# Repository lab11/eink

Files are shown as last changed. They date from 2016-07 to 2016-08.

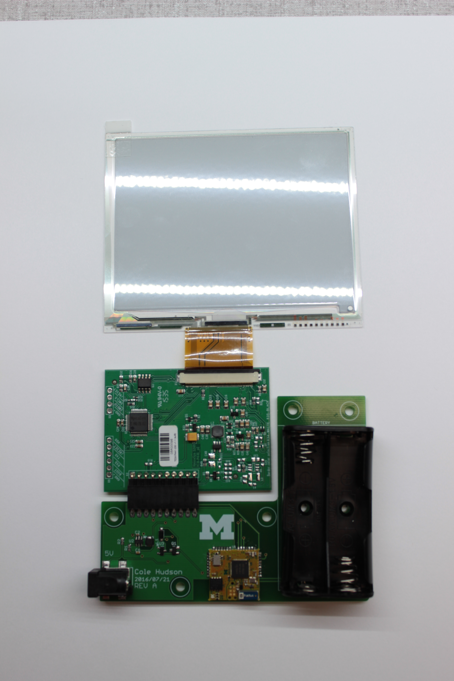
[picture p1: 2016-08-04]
media/IMG_8517.JPG

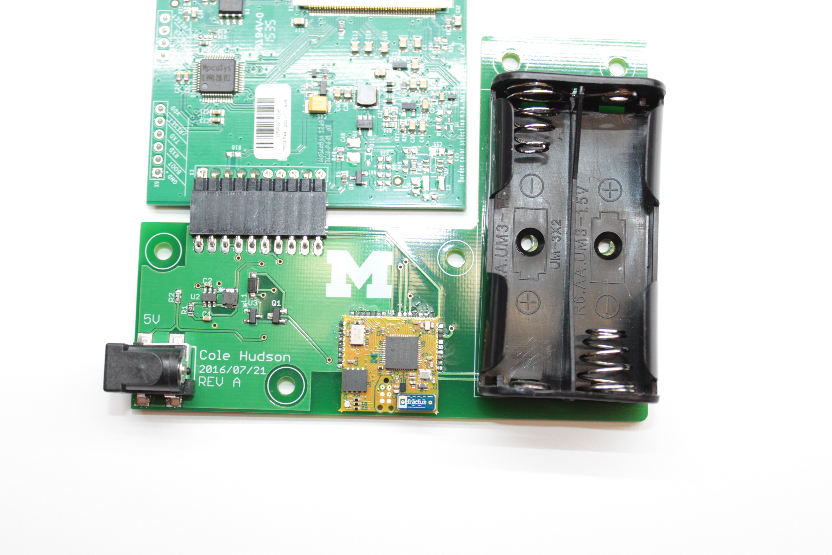
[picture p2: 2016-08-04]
media/IMG_8522.JPG

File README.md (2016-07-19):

# E-Ink
This is a BLE-controlled e-ink display built off of the nrf51822.

## Software
The nrf software can be found in ``` /software/nrf5x-base/apps/eink-advanced/ ```

## Summon App
[Summon](https://github.com/lab11/summon) is a UI application for BLE devices. Rather than requiring every user to install a new app for every BLE device, Summon allows BLE devices to point to their own HTML/JS based interface and loads it in a single application. Eink supports the summon architecture and provides a Summon application.

## Hardware
The hardware is built on top of the nrf51822. A full parts list can be found in the ``` /hardware ``` directory, along with pcb and case designs.

## API

| Characteristic name | uuid | Data Type | Range |
| --- | --- | --- | ---
| service | e528a44a-ff4f-3089-d44f-7cb505aba641 | None | |
| text | e528a410-ff4f-3089-d44f-7cb505aba641 | 20 byte packets up to 60 bytes | |
| x coordinate | e528a411-ff4f-3089-d44f-7cb505aba641 | uint16_t | 0 - 400 |
| y coordinate | e528a412-ff4f-3089-d44f-7cb505aba641 | uint16_t | 0 - 300 |
| scale | e528a413-ff4f-3089-d44f-7cb505aba641 | uint8_t | 0 - 10  |
| qrcode | e528a414-ff4f-3089-d44f-7cb505aba641 | 20 bytes | |
| control | e528a415-ff4f-3089-d44f-7cb505aba641 | uint8_t | |

#### Text
~~1. Break your text up into 19-byte packets.
2. Create an array of these packets.
3. For each packet, make the first byte equal to its distance from the last packet (the first byte of the first packet would be chunks.length - 1, the first byte of the last packet will be 0).
4. The remaining bytes will be the text packet.~~

**You can only write 18 characters at a time.**

#### Control
Writing 1 to control will refresh the display to show changes that have been made.
Writing 2 to control will clear the screen.

### Example

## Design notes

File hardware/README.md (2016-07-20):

#Parts

| Name | Price  | Link |
| --- | --- | --- |
| Eink Display | $66.00 | http://www.digikey.com/product-detail/en/ST044AS182/ST044AS182-ND/4898786 |
| Female headers  | $00.94 | http://www.digikey.com/product-detail/en/sullins-connector-solutions/PPTC101LGBN-RC/S5446-ND/775904 |
| Inductor | $00.48 | http://www.digikey.com/product-detail/en/murata-electronics-north-america/LQH43CN100K03L/490-2519-1-ND/599992 |
| 10uF capacitor  | $00.12 | http://www.digikey.com/product-detail/en/murata-electronics-north-america/GRM155R60G106ME44D/490-10693-1-ND/5251412 |
| 2.2uf capacitor | $00.12 | http://www.digikey.com/product-detail/en/murata-electronics-north-america/GRM188R61C225KE15D/490-3296-1-ND/702837 |
| Max6326 | $03.11 | http://www.digikey.com/product-detail/en/maxim-integrated/MAX6326UR29-T/MAX6326UR29-TCT-ND/2234432 |
| Mosfet | $00.39 | http://www.digikey.com/product-detail/en/fairchild-semiconductor/FDN340P/FDN340PCT-ND/965604 |
| Diode | $00.38 | http://www.digikey.com/product-detail/en/fairchild-semiconductor/SS15FA/SS15FACT-ND/5892131 |
| Barrel Jack | $01.89 | http://www.digikey.com/product-detail/en/cui-inc/PJ-002AH-SMT-TR/CP-002AHPJCT-ND/669692 |

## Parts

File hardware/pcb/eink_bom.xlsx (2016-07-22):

Qty | Value | Device | Package | Parts | Description | DIGIKEY | MPN | OC_FARNELL | OC_NEWARK | PACKAGE | PROD_ID | SF_ID | SUPPLIER | TOLERANCE | VALUE | WATTAGE
1 |  | DIODE[SCHOTKY]-SOD123W | SOD123W | D1 |  | SS15FACT-ND
1 |  | PINHD-1X10/90 | 1X10/90 | JP1 | PIN HEADER | S5446-ND
1 | 100K Ohms | RC0603JR-07100KL | RESC1608X60N | R1 | RESISTOR, 0603 | 311-100KGRCT-ND | RC0603JR-07100KL | 9233628 | 98K7287 |  |  |  | Yageo | ±5% | 100K Ohms | 1/10 W
1 | 100K Ohms | RC0603JR-07100KL | RESC1608X60N | R2 | RESISTOR, 0603 |  | RC0603JR-07100KL | 9233628 | 98K7287 |  |  |  | Yageo | ±5% | 100K Ohms | 1/10 W
1 | 10uF | CAPACITOR | 0402_CAP | C2 | 0402 Capacitor | 490-10693-1-ND
1 | 2.2uF | CAPACITOR | 0402_CAP | C1 | 0402 Capacitor | 490-3296-1-ND
1 | 5.5x2.1mm Barrel | POWER_JACKSMD | POWER_JACK_SMD | J2 | Power Jack | CP-002AHPJCT-ND |  |  |  |  | CONN-08106 | PRT-12748 |  |  | 5.5x2.1mm Barrel
1 | FDN340P | FDN340P | SSOT-3 | Q1 | P-Channel MOSFET | FDN340PCT-ND
1 | KEYSTONEELECTRONICS2462 | KEYSTONEELECTRONICS2462 | KEYSTONEELECTRONICS2462 | BATTERY |  | 36-2462-ND
1 | LTC3531ES6-3PBF | LTC3531ES6-3PBF | SOT95P280X100-6N | U2 | DC/DC Converters | LTC3531ES6-3.3#TRMPBFCT-ND | LTC3531ES6-3#PBF | - | 46P4583 | TSOT-23-6 |  |  | Linear Technology
1 | MAX6326UR29+ | MAX6326UR29+ | SOT95P228X119-3N | U3 | 3-Pin, Ultra-Low-Power SC70/SOT ìP Reset Circuits | MAX6326UR29+TCT-ND | MAX6326UR29+ | 9723951 | - | SOT-23-3 |  |  | Maxim
1 | NUCLEUM | NUCLEUM | NUCLEUM | U1 | Nucleum sensorboard prototyping module.
1 | UMICH_SOLID_LARGE | UMICH_SOLID_LARGE | UMICH_SOLID_350MIL | LOGO1
1 | VLF302510MT | VLF302510MT | VLF302510MT | L1 | POWER INDUCTOR | 445-6775-1-ND

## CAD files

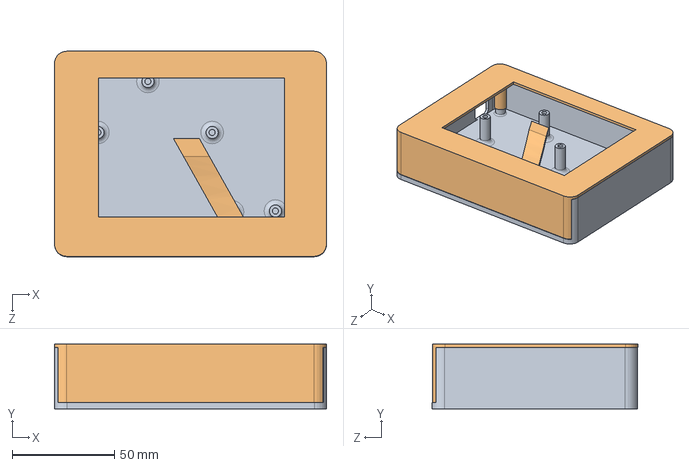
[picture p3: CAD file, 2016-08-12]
hardware/case/eink_assembly.SLDASM
133.3 x 31.8 x 100.8 mm
eink_controller_case_back_test
eink_controller_case_front_test2

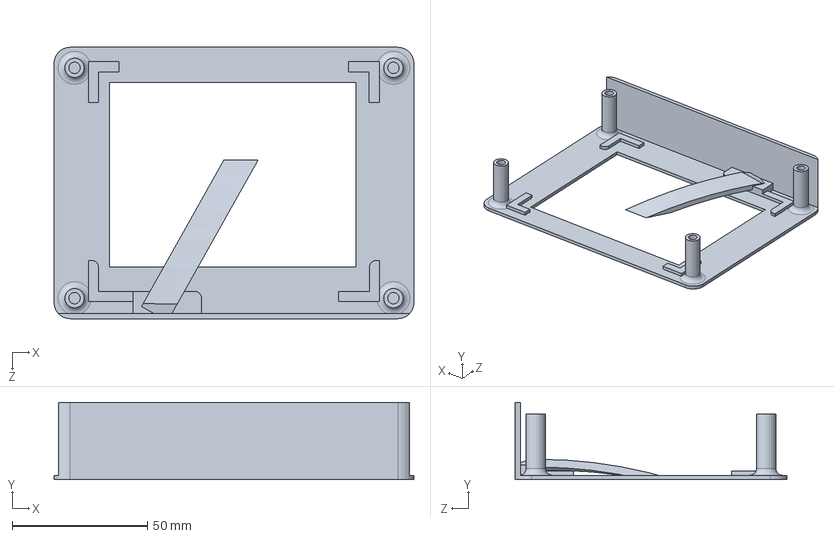
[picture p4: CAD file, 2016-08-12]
hardware/case/eink_controller_case_front_test2.SLDPRT
133.3 x 28.6 x 100.5 mm

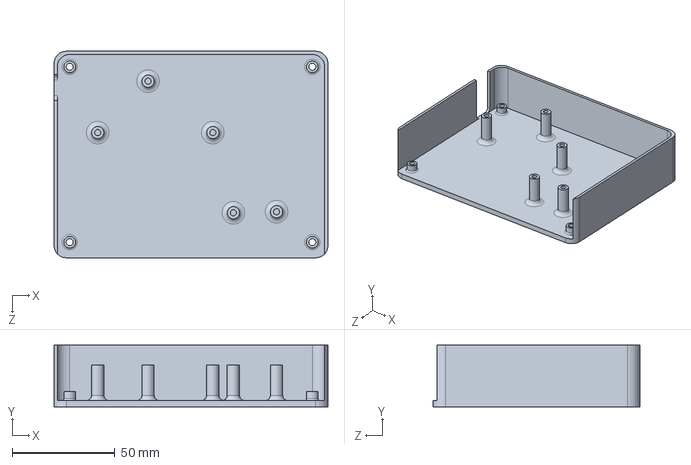
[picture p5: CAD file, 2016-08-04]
hardware/case/eink_controller_case_back_test.SLDPRT
133.3 x 30.2 x 100.5 mm

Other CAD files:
hardware/case/eink_controller_case_front.STL

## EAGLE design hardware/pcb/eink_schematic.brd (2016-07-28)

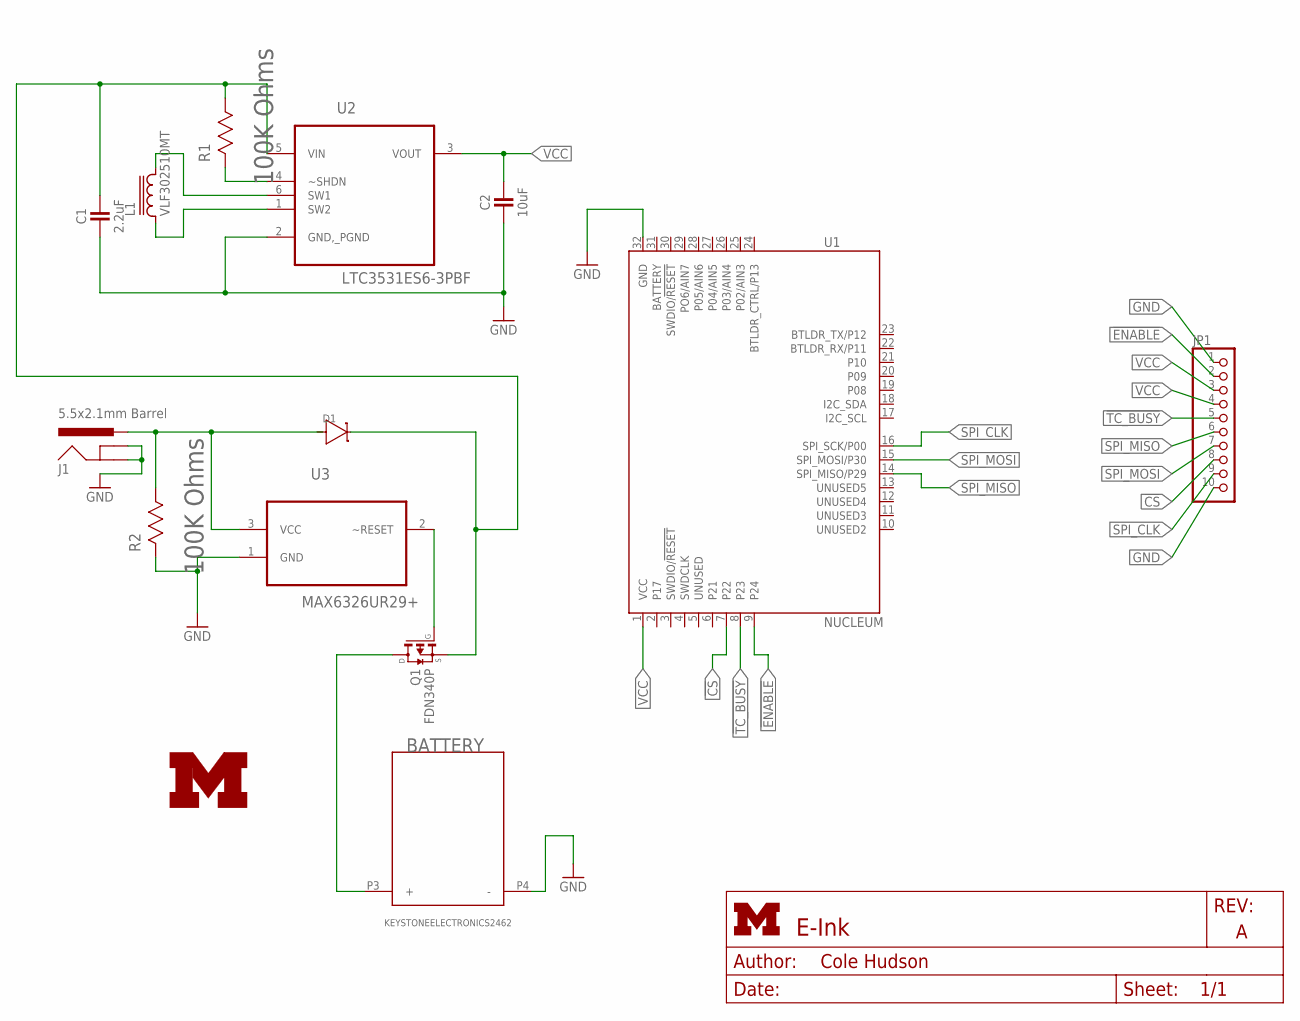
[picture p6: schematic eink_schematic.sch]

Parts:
BATTERY: KEYSTONEELECTRONICS2462; DIGIKEY 36-2462-ND
C1: 2.2uF; 0402_CAP; DIGIKEY 490-3296-1-ND
C2: 10uF; 0402_CAP; DIGIKEY 490-10693-1-ND
D1: DIODE[SCHOTKY]-SOD123W; SOD123W; DIGIKEY SS15FACT-ND
J1: 5.5x2.1mm Barrel; POWER_JACK_SMD; DIGIKEY CP-002AHPJCT-ND
JP1: PINHD-1X10/90; 1X10/90; DIGIKEY S5446-ND
L1: VLF302510MT; DIGIKEY 445-6775-1-ND
LOGO1: UMICH_SOLID_LARGE; UMICH_SOLID_350MIL
Q1: FDN340P; SSOT-3; DIGIKEY FDN340PCT-ND
R1: 100K Ohms; RESC1608X60N; DIGIKEY 311-100KGRCT-ND
R2: 100K Ohms; RESC1608X60N
U1: NUCLEUM
U2: LTC3531ES6-3PBF; SOT95P280X100-6N; DIGIKEY LTC3531ES6-3.3#TRMPBFCT-ND
U3: MAX6326UR29+; SOT95P228X119-3N; DIGIKEY MAX6326UR29+TCT-ND

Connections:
!CS: JP1.8, U1.7 (P22)
!ENABLE: JP1.2, U1.9 (P24)
!SHDN: R1.2 (R2), U2.4 (~SHDN)
!TC_BUSY: JP1.5, U1.8 (P23)
GND: BATTERY.P4 (-), C1.2, C2.2, J1.GND (GNDBREAK), J1.P$4 (GND), JP1.1, JP1.10, R2.2 (R2), U1.32 (GND), U2.2 (GND,_PGND), U3.1 (GND)
unnamed: Q1.1 (G), U3.2 (~RESET)
unnamed: D1.P$1 (1), J1.VIN0 (PWR), R2.1 (R1), U3.3 (VCC)
unnamed: C1.1, D1.P$2 (2), Q1.2 (S), R1.1 (R1), U2.5 (VIN)
unnamed: BATTERY.P3 (+), Q1.3 (D)
SPI_CLK: JP1.9, U1.16 (SPI_SCK/P00)
SPI_MISO: JP1.6, U1.14 (SPI_MISO/P29)
SPI_MOSI: JP1.7, U1.15 (SPI_MOSI/P30)
SW1: L1.2, U2.6 (SW1)
SW2: L1.1, U2.1 (SW2)
VCC: C2.1, JP1.3, JP1.4, U1.1 (VCC), U2.3 (VOUT)

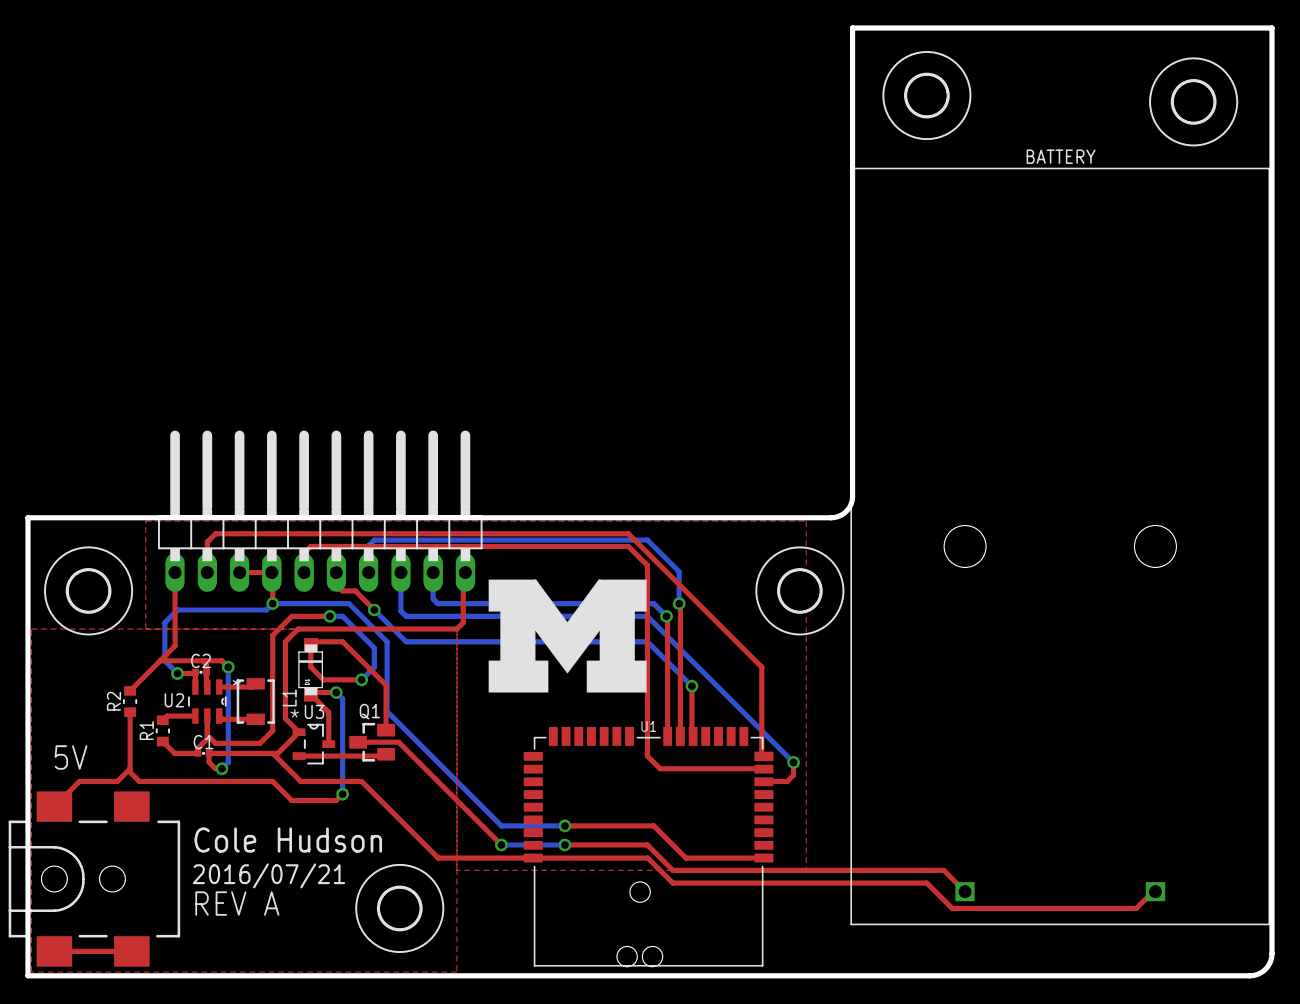
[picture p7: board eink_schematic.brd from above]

Board: 2 copper layers, 97.9 x 74.6 mm, 19 parts (0 on the bottom side), 15 nets.

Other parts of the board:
U$1, U$2, U$3, U$4, U$5: 3,2

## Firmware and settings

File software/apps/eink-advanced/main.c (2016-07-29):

#include <stdbool.h>
#include <stdint.h>

// Nordic libraries
#include "ble_advdata.h"
#include "nordic_common.h"
#include "softdevice_handler.h"

// nrf5x-base libraries
#include "simple_ble.h"
#include "simple_adv.h"
#include "led.h"
#include "device_info_service.h"

#include "eddystone.h"

#include "tcmp441.h"

// Define constants about this beacon.
#define DEVICE_NAME "E-Ink disp"
#define PHYSWEB_URL "goo.gl/pKiLW5"

#define LED0 18
#define LED1 19
#define LED2 20

// Intervals for advertising and connections
static simple_ble_config_t ble_config = {
    .platform_id       = 0x00,              // used as 4th octect in device BLE address
    .device_id         = DEVICE_ID_DEFAULT,
    .adv_name          = DEVICE_NAME,       // used in advertisements if there is room
    .adv_interval      = MSEC_TO_UNITS(500, UNIT_0_625_MS),
    .min_conn_interval = MSEC_TO_UNITS(500, UNIT_1_25_MS),
    .max_conn_interval = MSEC_TO_UNITS(1000, UNIT_1_25_MS)
};

// service and characteristic handles
//  UUID created by `uuidgen -r`
//  16-bit short uuid is 0x890f (bytes 12 and 13 of 128-bit UUID)
static simple_ble_service_t eink_service = {
    .uuid128 = {{0x41, 0xa6, 0xab, 0x05, 0xb5, 0x7c, 0x4f, 0xd4,
                 0x89, 0x30, 0x4f, 0xff, 0xa4, 0x4a, 0x28, 0xe5}}
};

//text x coordinate
static simple_ble_char_t text_x_coordinate_char = {.uuid16 = 0xa411};
static uint16_t text_x_coordinate_value = 0;

//text y coordinate
static simple_ble_char_t text_y_coordinate_char = {.uuid16 = 0xa412};
static uint16_t text_y_coordinate_value = 0;

//text scale
static simple_ble_char_t text_scale_char = {.uuid16 = 0xa413};
static uint8_t text_scale_value = 1;//default to 1

//text
static simple_ble_char_t text_char = {.uuid16 = 0xa410};
static char text_value[30] = {0};

//qr code
static simple_ble_char_t qrcode_char = {.uuid16 = 0xa414};
static char qrcode_value[52] = {0};

//control characteristic 
static simple_ble_char_t control_char = {.uuid16 = 0xa415};
static uint8_t control_value = 0;//0 = nothing, 1 = refresh, 2 = clear

static volatile uint8_t second=0;

// called automatically by simple_ble_init
void services_init (void) {
    // add led service
    simple_ble_add_service(&eink_service);

    //add text x coordinate
    simple_ble_add_characteristic(0, 1, 0, 0,
            2, (uint16_t*)&text_x_coordinate_value,
            &eink_service, &text_x_coordinate_char);

    //add text y coordinate
    simple_ble_add_characteristic(0, 1, 0, 0,
            2, (uint16_t*)&text_y_coordinate_value,
            &eink_service, &text_y_coordinate_char);

    //add text scale
    simple_ble_add_characteristic(0, 1, 0, 0,
            1, (uint8_t*)&text_scale_value,
            &eink_service, &text_scale_char);

    //add string
    simple_ble_add_characteristic(0, 1, 0, 0,
            30, (char*)&text_value,
            &eink_service, &text_char);

    //add qr code
    simple_ble_add_characteristic(0, 1, 0, 0,
            52, (char*)&qrcode_value,
            &eink_service, &qrcode_char);

    //add control char
    simple_ble_add_characteristic(0, 1, 0, 0,
            1, (uint8_t*)&control_value,
            &eink_service, &control_char);
}

void ble_evt_write(ble_evt_t* p_ble_evt) 
{
    if (simple_ble_is_char_event(p_ble_evt, &text_char)) 
    {
        tcmp441_writeStringAtLocation(text_value, text_x_coordinate_value, text_y_coordinate_value, text_scale_value);
    }
    else if(simple_ble_is_char_event(p_ble_evt, &control_char))
    {
        if(control_value == 1)
        {
            //refresh
            tcmp441_updateDisplay();
        }
        else if(control_value == 2)
        {
            //clear
            tcmp441_clearScreen();
            tcmp441_updateDisplay();
        }
    }
    else if(simple_ble_is_char_event(p_ble_evt, &qrcode_char))
    {
        tcmp441_writeQRcode(qrcode_value);
    }
}

void ble_evt_connected(ble_evt_t* p_ble_evt)
{
    led_on(LED0);
}

void ble_evt_disconnected(ble_evt_t* p_ble_evt)
{
    led_off(LED0);
}

int main(void) 
{
    //set up the led, spi, and bluetooth
    tcmp441_init(18, 19, 20, 24, 23, 22);

    //write to the screen array and then update the display
    //writeQRcode("http://eecs.umich.edu");
    //updateDisplay();

    simple_ble_init(&ble_config);
    simple_adv_only_name();

    //advertise url
    eddystone_adv(PHYSWEB_URL, NULL);

    //writeStringAtLocation("Booted up", 0, 0, 2);
    //updateDisplay();

    //led_on(LED0);

    tcmp441_clearScreen();
    tcmp441_updateDisplay();

    // Enter main loop.
    while (1) {
        sd_app_evt_wait();
        //power_manage();
    }
}

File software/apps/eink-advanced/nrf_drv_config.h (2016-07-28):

/* Copyright (c) 2015 Nordic Semiconductor. All Rights Reserved.
 *
 * The information contained herein is property of Nordic Semiconductor ASA.
 * Terms and conditions of usage are described in detail in NORDIC
 * SEMICONDUCTOR STANDARD SOFTWARE LICENSE AGREEMENT.
 *
 * Licensees are granted free, non-transferable use of the information. NO
 * WARRANTY of ANY KIND is provided. This heading must NOT be removed from
 * the file.
 *
 */

#ifndef NRF_DRV_CONFIG_H
#define NRF_DRV_CONFIG_H

/**
 * Provide a non-zero value here in applications that need to use several
 * peripherals with the same ID that are sharing certain resources
 * (for example, SPI0 and TWI0). Obviously, such peripherals cannot be used
 * simultaneously. Therefore, this definition allows to initialize the driver
 * for another peripheral from a given group only after the previously used one
 * is uninitialized. Normally, this is not possible, because interrupt handlers
 * are implemented in individual drivers.
 * This functionality requires a more complicated interrupt handling and driver
 * initialization, hence it is not always desirable to use it.
 */
#define PERIPHERAL_RESOURCE_SHARING_ENABLED  0

/* CLOCK */
#define CLOCK_ENABLED 0

#if (CLOCK_ENABLED == 1)
#define CLOCK_CONFIG_XTAL_FREQ          NRF_CLOCK_XTALFREQ_Default
#define CLOCK_CONFIG_LF_SRC             NRF_CLOCK_LF_SRC_Xtal
#define CLOCK_CONFIG_IRQ_PRIORITY       APP_IRQ_PRIORITY_LOW
#endif

/* GPIOTE */
#define GPIOTE_ENABLED 1

#if (GPIOTE_ENABLED == 1)
#define GPIOTE_CONFIG_USE_SWI_EGU false
#define GPIOTE_CONFIG_IRQ_PRIORITY APP_IRQ_PRIORITY_LOW
#define GPIOTE_CONFIG_NUM_OF_LOW_POWER_EVENTS 1
#endif

/* TIMER */
#define TIMER0_ENABLED 0

#if (TIMER0_ENABLED == 1)
#define TIMER0_CONFIG_FREQUENCY    NRF_TIMER_FREQ_16MHz
#define TIMER0_CONFIG_MODE         TIMER_MODE_MODE_Timer
#define TIMER0_CONFIG_BIT_WIDTH    TIMER_BITMODE_BITMODE_32Bit
#define TIMER0_CONFIG_IRQ_PRIORITY APP_IRQ_PRIORITY_LOW

#define TIMER0_INSTANCE_INDEX      0
#endif

#define TIMER1_ENABLED 0

#if (TIMER1_ENABLED == 1)
#define TIMER1_CONFIG_FREQUENCY    NRF_TIMER_FREQ_16MHz
#define TIMER1_CONFIG_MODE         TIMER_MODE_MODE_Timer
#define TIMER1_CONFIG_BIT_WIDTH    TIMER_BITMODE_BITMODE_16Bit
#define TIMER1_CONFIG_IRQ_PRIORITY APP_IRQ_PRIORITY_LOW

#define TIMER1_INSTANCE_INDEX      (TIMER0_ENABLED)
#endif

#define TIMER2_ENABLED 0

#if (TIMER2_ENABLED == 1)
#define TIMER2_CONFIG_FREQUENCY    NRF_TIMER_FREQ_16MHz
#define TIMER2_CONFIG_MODE         TIMER_MODE_MODE_Timer
#define TIMER2_CONFIG_BIT_WIDTH    TIMER_BITMODE_BITMODE_16Bit
#define TIMER2_CONFIG_IRQ_PRIORITY APP_IRQ_PRIORITY_LOW

#define TIMER2_INSTANCE_INDEX      (TIMER1_ENABLED+TIMER0_ENABLED)
#endif

#define TIMER3_ENABLED 0

#if (TIMER3_ENABLED == 1)
#define TIMER3_CONFIG_FREQUENCY    NRF_TIMER_FREQ_16MHz
#define TIMER3_CONFIG_MODE         TIMER_MODE_MODE_Timer
#define TIMER3_CONFIG_BIT_WIDTH    TIMER_BITMODE_BITMODE_16Bit
#define TIMER3_CONFIG_IRQ_PRIORITY APP_IRQ_PRIORITY_LOW

#define TIMER3_INSTANCE_INDEX      (TIMER2_ENABLED+TIMER1_ENABLED+TIMER0_ENABLED)
#endif

#define TIMER4_ENABLED 0

#if (TIMER4_ENABLED == 1)
#define TIMER4_CONFIG_FREQUENCY    NRF_TIMER_FREQ_16MHz
#define TIMER4_CONFIG_MODE         TIMER_MODE_MODE_Timer
#define TIMER4_CONFIG_BIT_WIDTH    TIMER_BITMODE_BITMODE_16Bit
#define TIMER4_CONFIG_IRQ_PRIORITY APP_IRQ_PRIORITY_LOW

#define TIMER4_INSTANCE_INDEX      (TIMER3_ENABLED+TIMER2_ENABLED+TIMER1_ENABLED+TIMER0_ENABLED)
#endif


#define TIMER_COUNT (TIMER0_ENABLED + TIMER1_ENABLED + TIMER2_ENABLED + TIMER3_ENABLED + TIMER4_ENABLED)

/* RTC */
#define RTC0_ENABLED 0

#if (RTC0_ENABLED == 1)
#define RTC0_CONFIG_FREQUENCY    32678
#define RTC0_CONFIG_IRQ_PRIORITY APP_IRQ_PRIORITY_LOW
#define RTC0_CONFIG_RELIABLE     false

#define RTC0_INSTANCE_INDEX      0
#endif

#define RTC1_ENABLED 0

#if (RTC1_ENABLED == 1)
#define RTC1_CONFIG_FREQUENCY    32768
#define RTC1_CONFIG_IRQ_PRIORITY APP_IRQ_PRIORITY_LOW
#define RTC1_CONFIG_RELIABLE     false

#define RTC1_INSTANCE_INDEX      (RTC0_ENABLED)
#endif

#define RTC_COUNT                (RTC0_ENABLED+RTC1_ENABLED)

#define NRF_MAXIMUM_LATENCY_US 2000

/* RNG */
#define RNG_ENABLED 0

#if (RNG_ENABLED == 1)
#define RNG_CONFIG_ERROR_CORRECTION true
#define RNG_CONFIG_POOL_SIZE        8
#define RNG_CONFIG_IRQ_PRIORITY     APP_IRQ_PRIORITY_LOW
#endif

/* PWM */

#define PWM0_ENABLED 0

#if (PWM0_ENABLED == 1)
#define PWM0_CONFIG_OUT0_PIN        2
#define PWM0_CONFIG_OUT1_PIN        3
#define PWM0_CONFIG_OUT2_PIN        4
#define PWM0_CONFIG_OUT3_PIN        5
#define PWM0_CONFIG_IRQ_PRIORITY    APP_IRQ_PRIORITY_LOW
#define PWM0_CONFIG_BASE_CLOCK      NRF_PWM_CLK_1MHz
#define PWM0_CONFIG_COUNT_MODE      NRF_PWM_MODE_UP
#define PWM0_CONFIG_TOP_VALUE       1000
#define PWM0_CONFIG_LOAD_MODE       NRF_PWM_LOAD_COMMON
#define PWM0_CONFIG_STEP_MODE       NRF_PWM_STEP_AUTO

#define PWM0_INSTANCE_INDEX 0
#endif

#define PWM1_ENABLED 0
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

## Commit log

2016-06-29 Switched to cordova stuff and then reverted back
2016-06-29 switched to old bluetooth file
2016-06-29 No longer tries to set deviceid in html
2016-06-29 rev17: attempt to connect to device
2016-06-30 rev29: switched back to normal write
2016-06-30 rev48: log device and attached characteristics
2016-07-01 rev52: print characteristics after successful connection
2016-07-01 rev53: connect to different device
2016-07-01 rev54: replaced deviceId with bleAddress
2016-07-01 rev57: set char uuids to printout from previous run
2016-07-01 rev58: switched back to normal write @Don Coleman
2016-07-02 Created eagle project + schematic
    [eink_schematic.sch]
2016-07-05 rev70: disconnect from device after successful write
2016-07-12 rev78: just try writing text
    [eink_schematic.sch]
2016-07-13 rev80: switched to using rawgit cdn
2016-07-13 rev81: switched back to trying to write everything in succession, not just text
2016-07-13 rev82: print scan number
2016-07-13 rev85: don't disconnect from device between writes
2016-07-13 rev91: disconnect from device.id, not device
2016-07-14 rev112: switched back to staying connected
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2016-07-15 rev129: removed reference to device in writeBuffer failure
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2016-07-19 Eagle: labeled B3-5 and SPI pins
    [eink_schematic.brd, eink_schematic.sch]
2016-07-19 Eagle: Added headers and labeled more
    [eink_schematic.sch]
2016-07-19 added buck/boost regulator to schematic
    [eink_schematic.brd, eink_schematic.sch]
2016-07-20 Added some libs, buck/boost regulator, and barrel jack
    [eink_schematic.brd, eink_schematic.sch]
2016-07-20 Created L-shaped board
    [eink_schematic.brd]
2016-07-20 added digikey part numbers for everything
    [eink_schematic.brd, eink_schematic.sch]
2016-07-20 Eagle: pretty sure I got things wired up
    [eink_schematic.brd, eink_schematic.sch]
2016-07-21 deleted traces from 1st try
    [eink_schematic.brd]
2016-07-21 Traces try #2 looks much better
    [eink_schematic.brd]
2016-07-21 Corrected spacing
    [eink_schematic.brd]
2016-07-21 centered board on origin and added measurements
    [eink_schematic.brd]
2016-07-21 re-wired and created eagle part for through-hole battery pack
    [eink_schematic.brd, eink_schematic.sch]
2016-07-22 wiring is good + added GND plane
    [eink_schematic.brd]
2016-07-22 Measurements all check out
    [eink_schematic.brd]
2016-07-22 redid battery
    [eink_schematic.brd, eink_schematic.sch]
2016-07-22 generated gerbers and re-numbered
    [eink_rev_a.csv, eink_schematic.brd, eink_schematic.sch]
2016-07-22 started running brad's python scripts
    [bom.csv, bom.xls, bom.xlsx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]
2016-07-22 Submitted order
    [bom.xls, bom.xlsx, eink_bom.csv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]
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2016-07-26 started designing case
    [eink_controller_case.SLDPRT]
2016-07-26 added screen dimensions and wall dimensions
    [eink_controller_case.SLDPRT]
2016-07-26 tried printing a corner. DON'T DO OVERHANGS
    [eink_controller_case.SLDPRT, eink_controller_case_front_test.SLDPRT, eink_controller_case_front_test.STL]
2016-07-27 Added screw holes
    [eink_controller_case_front_test.SLDPRT, eink_controller_case_front_test2.SLDPRT]
2016-07-27 Added back of case
    [eink_controller_case_back_test.SLDPRT, eink_controller_case_front_test2.SLDPRT]
2016-07-27 Started adding screw holes to the case back
    [eink_controller_case_back_test.SLDPRT]
2016-07-27 front and back holes to connect
    [eink_controller_case_back_test.SLDPRT, eink_controller_case_front_test2.SLDPRT]
2016-07-27 Added chamfered holes
    [eink_controller_case_back_test.SLDPRT, eink_controller_case_front_test2.SLDPRT]
2016-07-28 started adding mounting points for pcb
    [eink_controller_case_back_test.SLDPRT, eink_controller_case_front_test2.SLDPRT]
2016-07-28 Added mounting points for the pcb and extruded
    [eink_controller_case_back_test.SLDPRT]
2016-07-28 Added extrusion to hold display in place from the back
    [eink_controller_case_back_test.SLDPRT, eink_controller_case_front_test2.SLDPRT]
2016-07-28 Added 6mm edge fillet
    [eink_controller_case_back_test.SLDPRT, eink_controller_case_front_test2.SLDPRT]
2016-07-28 Added noble app. Connect and get occupancy value
    [eink_schematic.brd]
2016-07-28 Started printing case. Generated STLs
    [back.STL, eink_controller_case_back_test.SLDPRT, eink_controller_case_front_test2.SLDPRT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]
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2016-07-28 Combined eink-advanced with service-example. Turning the led on also activates the eink display
2016-07-28 hopefully fixed nrf_gpio_pin_clear(nTC_EN) issue
    [main.c]
2016-07-28 fixed font8x8 submodule issue
    [main.c]
2016-07-29 Fixed diameter/radius problems (hopefully)
    [eink_assembly.SLDASM, eink_controller_case_back_good.STL, eink_controller_case_back_test.SLDPRT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]
2016-08-03 Added hole for barrel jack
    [eink_controller_case_back_test.SLDPRT]
2016-08-03 fillet hole for barrel jack
    [eink_controller_case_back_test.SLDPRT]
2016-08-04 converted pegs into screw-mounting holes
    [eink_controller_case_back_test.SLDPRT]
2016-08-04 fillet on those screw holes
    [eink_controller_case_back_test.SLDPRT]
2016-08-04 Started printing case after most recent changes
    [back.STL, eink_assembly.SLDASM, eink_controller_back.STL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]
2016-08-04 Added fillet on top part of case for the connecting pegs
    [eink_controller_case_front_test2.SLDPRT]
2016-08-08 Added extruded piece to hold display in place
    [eink_controller_case_front.STL, eink_controller_case_front_test2.SLDPRT]
2016-08-08 moved display holder off to the side to avoid ribbon cable
    [eink_controller_case_front_test2.SLDPRT]
2016-08-09 added top brackets for display and fixed fillet on bottom corners
    [eink_assembly.SLDASM, eink_controller_back.STL, eink_controller_case_front.STL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]
2016-08-11 improved case
    [eink_controller_case_front.STL, eink_controller_case_front_test2.SLDPRT]

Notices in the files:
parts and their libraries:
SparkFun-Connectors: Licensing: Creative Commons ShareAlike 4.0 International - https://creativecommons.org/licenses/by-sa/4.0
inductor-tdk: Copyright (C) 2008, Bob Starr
